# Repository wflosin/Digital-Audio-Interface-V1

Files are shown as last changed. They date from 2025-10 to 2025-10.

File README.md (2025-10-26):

This is a complete design for a digital audio interface. The features include:
- 1/4" jack input (mono)
- Headphone output (loobpack or computer audio output)
- Active tone control, three knobs (bass, mid, treble) 
- Active volume control
- Clipping indicator
- HID buttons (mute, volume up, volume down)
- Entirely USB-powered
- No screws needed, the panel snap fits into the enclosure

What is found in this repository:
- Schematic and Board files (Eagle CAD)
- Images of the schematic and board
- Parts list, and Digikey order
- Gerber files
- 3D models for the enclosure, and potentiometer and button caps

The circuit uses the audio codex PCM2906 from TI, which includes a USB interface. Although many of the parts can be hand-soldered, it is recoommended to reflow solder the board. 

The overall cost of parts and printing was approximately $115 CAD (Oct-2025). Parts were selected to minimize noise thorughout the circuit, and so cheaper alternatives could be used instead. 
Parts were ordered through Digikey and from Texas Instruments. The enclosure was 3D printed, but a metal enclosure could probe useful for shielding. 

Notable issues to be improved on in the next iteration: 
- Headphone pop when plugging in
- When the bass tone control is turned up too high, all sound cuts out
- When listening through headphones on the loobback setting, the only way to control the headphone volume is with the gain knob. This should have a separate volume control. 

Noise and performance metrics of the board were not evaluated once completed. Audio quality was sufficient for this iteration, but naturally, performance metrics are a must potentially commercializable devices. 

I hope you like it!

Below are several sources that helped in the creation of this design:
- https://www.theseus.fi/bitstream/handle/10024/857714/Heikkinen_Tuomas-Pyry.pdf
- https://kastner.ucsd.edu/ryan/wp-content/uploads/sites/5/2022/06/admin/usb-audio-interface.pdf
- https://guitarnuts2.proboards.com/thread/7842/modeling-electric-guitar-ltspice
- https://circuitdigest.com/electronic-circuits/audio-equalizer-tone-control-circuit-with-bass-treble-and-mid-frequency-control
- https://www.ti.com/lit/ug/tidu034/tidu034.pdf
- Small Signal Audio Design, by Douglas Self (chapter 9)
- https://www.edn.com/signal-distortion-from-high-k-ceramic-capacitors/

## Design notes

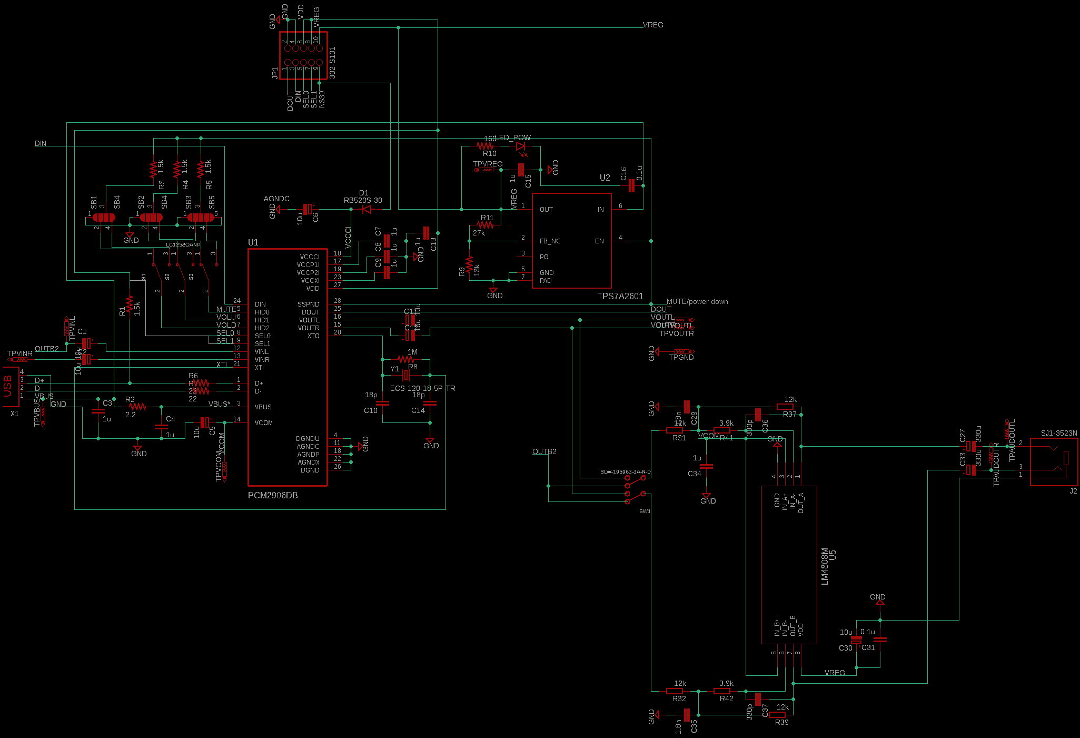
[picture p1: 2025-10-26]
DAI_V1.1_schematic_sheet1.png

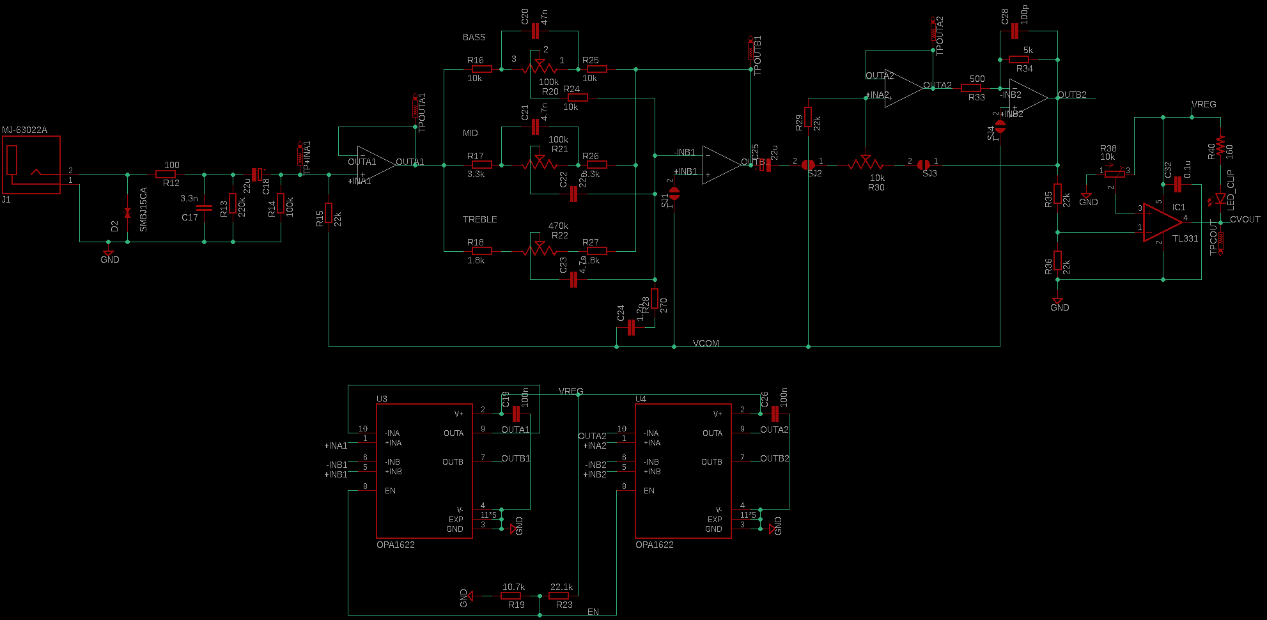
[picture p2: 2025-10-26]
DAI_V1.1_schematic_sheet2.png

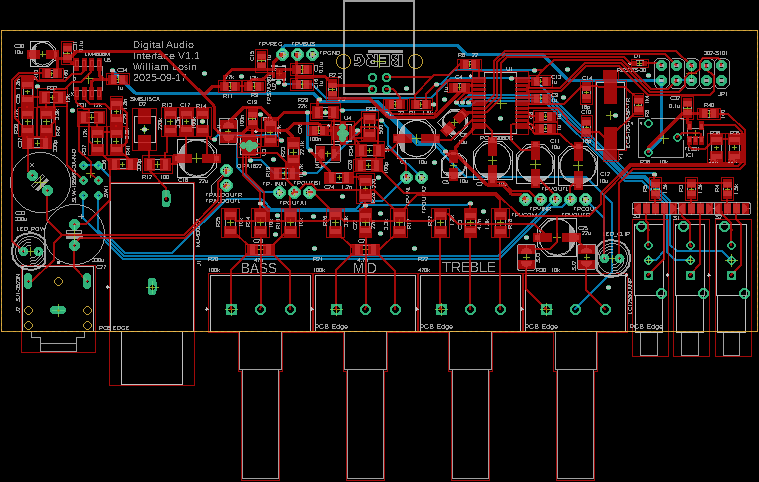
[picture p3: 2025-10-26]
DAI_V1.1_board.png

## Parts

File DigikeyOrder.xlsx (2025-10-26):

# | QUANTITY | PART NUMBER | MANUFACTURER PART NUMBER | DESCRIPTION | CUSTOMER REFERENCE | BACKORDER | UNIT PRICE | EXTENDED PRICE
1 | 1 | 118-PDB181-K425K-103B-ND | PDB181-K425K-103B | POT 10K OHM 1/5W CARBON LINEAR |  | 0 | 1.89 | 1.89
2 | 2 | 2223-PTN16-A100125K1B1-ND | PTN16-A100125K1B1 | POT 100K OHM 1/8W CARBON LINEAR |  | 0 | 1.76 | 3.52
3 | 1 | 2223-PTN16-A500125K1B1-ND | PTN16-A500125K1B1 | POT 500K OHM 1/8W CARBON LINEAR |  | 0 | 1.76 | 1.76
4 | 1 | 609-3657-ND | 61729-1011BLF | CONN RCPT USB2.0 TYPEB 4POS R/A |  | 0 | 1.7 | 1.70
5 | 4 | 732-5317-ND | 61300411121 | CONN HEADER VERT 4POS 2.54MM |  | 0 | 0.25 | 1.00
6 | 10 | 2057-RS1-02-G-ND | RS1-02-G | RECEPTACLE STRIP 2P 2.54MM PITCH |  | 0 | 0.207 | 2.07
7 | 1 | XC717CT-ND | ECS-120-18-5P-TR | CRYSTAL 12.0000MHZ 18PF SMD |  | 0 | 1.1 | 1.10
8 | 3 | EG5887-ND | LC1258OANP | SWITCH PUSHBUTTON SPDT 0.3A 30V |  | 0 | 1.65 | 4.95
9 | 1 | CP1-3523N-ND | SJ1-3523N | CONN JACK STEREO 3.5MM R/A |  | 0 | 1.21 | 1.21
10 | 1 | RB520S-30-TPMSCT-ND | RB520S-30-TP | DIODE SCHOTTKY 30V 200MA SOD523 |  | 0 | 0.25 | 0.25
11 | 1 | SMBJ15CALFCT-ND | SMBJ15CA | TVS DIODE 15VWM 24.4VC DO214AA |  | 0 | 0.52 | 0.52
12 | 1 | 296-10168-1-ND | TL331IDBVR | IC COMPARATOR 1 DIFF SOT23-5 |  | 0 | 0.67 | 0.67
13 | 1 | 754-1217-ND | WP3A8GD | LED GREEN DIFFUSED T-1 T/H |  | 0 | 0.33 | 0.33
14 | 1 | 754-1212-ND | WP132XYD | LED YELLOW DIFFUSED T-1 T/H |  | 0 | 0.4 | 0.40
15 | 1 | 2223-SLW-195963-3A-N-D-ND | SLW-195963-3A-N-D | 19.5 X 9 X 6.3 MM, 3 MM RAISED S |  | 0 | 0.68 | 0.68
16 | 2 | 493-15141-ND | UFW1H331MPD | CAP ALUM 330UF 20% 50V RADIAL TH |  | 0 | 1.12 | 2.24
17 | 1 | ED1543-ND | 302-S101 | CONN HEADER VERT 10POS 2.54MM |  | 0 | 0.38 | 0.38
18 | 1 | 2223-MJ-63022A-ND | MJ-63022A | AUDIO JACK, 6.35 MM, HORIZONTAL, |  | 0 | 1.85 | 1.85
19 | 1 | 296-35280-1-ND | LM4808MX/NOPB | IC AMP CLASS AB STER 150MW 8SOIC |  | 0 | 1.24 | 1.24
20 | 1 | 541-4192-1-ND | CRCW1206270RFKEAC | RES SMD 270 OHM 1% 1/4W 1206 | R28 | 0 | 0.16 | 0.16
21 | 1 | 118-CR1206-FX-5100ELFCT-ND | CR1206-FX-5100ELF | RES SMD 510 OHM 1% 1/4W 1206 | R33 | 0 | 0.16 | 0.16
22 | 2 | 311-1.80KFRCT-ND | RC1206FR-071K8L | RES 1.8K OHM 1% 1/4W 1206 | R18, R27 | 0 | 0.16 | 0.32
23 | 2 | 541-4191-1-ND | CRCW12063K30FKEAC | RES SMD 3.3K OHM 1% 1/4W 1206 | R17, R26 | 0 | 0.16 | 0.32
24 | 1 | CR1206-FX-5101ELFCT-ND | CR1206-FX-5101ELF | RES SMD 5.1K OHM 1% 1/4W 1206 | R34 | 0 | 0.16 | 0.16
25 | 3 | 311-10.0KFRCT-ND | RC1206FR-0710KL | RES 10K OHM 1% 1/4W 1206 | R16, R24, R25 | 0 | 0.16 | 0.48
26 | 4 | A129826CT-ND | CRGCQ1206F22K | RES 22K OHM 1% 1/4W 1206 | R15, R29/R35, R36 | 0 | 0.16 | 0.64
27 | 1 | 311-100KFRCT-ND | RC1206FR-07100KL | RES 100K OHM 1% 1/4W 1206 | R14 | 0 | 0.16 | 0.16
28 | 1 | 311-220KFRCT-ND | RC1206FR-07220KL | RES 220K OHM 1% 1/4W 1206 | R13 | 0 | 0.16 | 0.16
29 | 2 | RMCF1206FT3K90CT-ND | RMCF1206FT3K90 | RES 3.9K OHM 1% 1/4W 1206 | R41, R42 | 0 | 0.16 | 0.32
30 | 1 | P20755CT-ND | ERJ-PB6B2702V | RES SMD 27K OHM 0.1% 1/4W 0805 | R11 | 0 | 0.33 | 0.33
31 | 1 | P20720CT-ND | ERJ-PB6B1302V | RES SMD 13K OHM 0.1% 1/4W 0805 | R9 | 0 | 0.33 | 0.33
32 | 2 | 2019-RK73H2ATTD1600FCT-ND | RK73H2ATTD1600F | RES 160 OHM 1% 1/4W 0805 | R10, R40 | 0 | 0.16 | 0.32
33 | 1 | 2019-RK73H2ATTD2R20FCT-ND | RK73H2ATTD2R20F | RES 2.2 OHM 1% 1/4W 0805 | R2 | 0 | 0.16 | 0.16
34 | 2 | 2019-RK73H2ATTD22R0FCT-ND | RK73H2ATTD22R0F | RES 22 OHM 1% 1/4W 0805 | R6, R7 | 0 | 0.16 | 0.32
35 | 1 | 2019-RK73H2ATTD1004FCT-ND | RK73H2ATTD1004F | RES 1M OHM 1% 1/4W 0805 | R8 | 0 | 0.16 | 0.16
36 | 4 | 2019-RK73H2ATTD1501FCT-ND | RK73H2ATTD1501F | RES 1.5K OHM 1% 1/4W 0805 | R1, R3, R4, R5 | 0 | 0.16 | 0.64
37 | 1 | 2019-RK73H2BTTD1072FCT-ND | RK73H2BTTD1072F | RES 10.7K OHM 1% 1/4W 1206 | R19 | 0 | 0.16 | 0.16
38 | 1 | 2019-RK73H2BTTD2212FCT-ND | RK73H2BTTD2212F | RES 22.1K OHM 1% 1/4W 1206 | R23 | 0 | 0.16 | 0.16
39 | 10 | 2019-RK73H2BTTD1202FCT-ND | RK73H2BTTD1202F | RES 12K OHM 1% 1/4W 1206 | R31, R32, R37, R39 | 0 | 0.061 | 0.61
40 | 1 | 1276-3259-1-ND | CL31C332JHHNFNE | CAP CER 3300PF 630V C0G/NP0 1206 | C17 | 0 | 0.2 | 0.20
41 | 2 | 490-GCM3195C2A472GA16DCT-ND | GCM3195C2A472GA16D | CAP CER 4700PF 100V C0G/NP0 1206 | C21, C23 | 0 | 0.36 | 0.72
42 | 1 | 490-GRM3195C2A473GA01DCT-ND | GRM3195C2A473GA01D | CAP CER 47000PF 100V C0G 1206 | C20 | 0 | 0.96 | 0.96
43 | 1 | 490-GRT3195C2A223JA02DCT-ND | GRT3195C2A223JA02D | CAP CER 0.022UF 100V C0G 1206 | C22 | 0 | 0.51 | 0.51
44 | 1 | 13-CC1206FRNPO9BN122CT-ND | CC1206FRNPO9BN122 | CAP CER 1200PF 50V C0G/NPO 1206 | C24 | 0 | 0.66 | 0.66
45 | 1 | 720-VJ1206A101JXGCW1HVCT-ND | VJ1206A101JXGCW1HV | CAP CERAMIC 100PF 1KV C0G NP0 | C28 | 0 | 0.19 | 0.19
46 | 2 | 13-CC1206GRNPO9BN182CT-ND | CC1206GRNPO9BN182 | CAP CER 1800PF 50V C0G/NPO 1206 | C29, C35 | 0 | 0.5 | 1.00
47 | 2 | 1276-1846-1-ND | CL31C331JBCNNNC | CAP CER 330PF 50V C0G/NP0 1206 | C36, C37 | 0 | 0.22 | 0.44
48 | 4 | 732-8327-1-ND | 865250643009 | CAP ALUM 10UF 20% 50V SMD | C1, C2/C11, C12 | 0 | 0.58 | 2.32
49 | 2 | 732-8353-1-ND | 865250543005 | CAP ALUM 22UF 20% 35V SMD | C18, C25 | 0 | 0.6 | 1.20
50 | 3 | 732-8430-1-ND | 865080440002 | CAP ALUM 10UF 20% 25V SMD | C5, C6, C30 | 0 | 0.26 | 0.78
51 | 10 | 1276-1029-1-ND | CL21B105KBFNNNE | CAP CER 1UF 50V X7R 0805 | C3, C4, C7, C8, C9, C13, C15, C34 | 0 | 0.019 | 0.19
52 | 10 | 478-KGM21NR71H104KTCT-ND | KGM21NR71H104KT | CAP CER 0.1UF 50V X7R 0805 | C16, C19, C26, C31, C32 | 0 | 0.013 | 0.13
53 | 2 | 311-1102-1-ND | CC0805JRNPO9BN180 | CAP CER 18PF 50V C0G/NPO 0805 | C10, C14 | 0 | 0.15 | 0.30
54 | 1 | 311-100FRCT-ND | RC1206FR-07100RL | RES 100 OHM 1% 1/4W 1206 | R12 | 0 | 0.16 | 0.16

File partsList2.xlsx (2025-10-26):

Partlist
Exported from DAI_V1.brd at 2025-09-17 1:20 AM
 |  |  | Components on audio path
EAGLE Version 9.6.2 Copyright (c) 1988-2020 Autodesk, Inc. |  |  | Page 2
 |  |  | Page 1
Assembly variant:
 |  |  |  |  |  |  | $40.52
 |  |  |  |  |  |  | $68.78
Part | Value | Device | Description | Price per unit | Required quantity | Tentative quantity | Total Cost | Aquired | Link
R2 | 2.2 | RES 2.2 OHM 1% 1/4W 0805 | VBUS | $0.16 | 1 | 1 | $0.16
R6, R7 | 22 | RES 22 OHM 1% 1/4W 0805 | USB data | $0.16 | 2 | 2 | $0.32
R12 | 100 | RES 100 OHM 1% 1/4W 1206 | RF Filter | $0.16 | 1 | 1 | $0.16
R10, R40 | 160 | RES 160 OHM 1% 1/4W 0805 | LED Resistors | $0.16 | 2 | 2 | $0.32
R28 | 270 | RES SMD 270 OHM 1% 1/4W 1206 | Tone EQ | $0.16 | 1 | 1 | $0.16
R33 | 510 | RES SMD 510 OHM 1% 1/4W 1206 | Baxandall | $0.16 | 1 | 1 | $0.16
C16, C19, C26, C31, C32 | 0.1u | CAP CER 0.1UF 50V X7R 0805 | Bypass caps | $0.01 | 5 | 10 | $0.13
C24 | 1.2n | CAP CER 1200PF 50V C0G/NPO 1206 | Tone EQ | $0.66 | 1 | 1 | $0.66
R1, R3, R4, R5 | 1.5k | RES 1.5K OHM 1% 1/4W 0805 | Pullup? | $0.16 | 4 | 4 | $0.64
R18, R27 | 1.8k | RES 1.8K OHM 1% 1/4W 1206 | Treble | $0.16 | 2 | 2 | $0.32
C29, C35 | 1.8n | CAP CER 1800PF 50V C0G/NPO 1206 | Headphone caps, C0G | $0.50 | 2 | 2 | $1.00
R19 | 10.7k | RES 10.7K OHM 1% 1/4W 1206 | EN stabilizer | $0.16 | 1 | 1 | $0.16
R14 | 100k | RES 100K OHM 1% 1/4W 1206 | RF Filter | $0.16 | 1 | 1 | $0.16
R20, R21 | 100k | POT_PTN16-A100125K1B1 | rotary potentiometer | $1.76 | 2 | 2 | $3.52
C28 | 100p | CAP CERAMIC 100PF 1KV C0G NP0 | Baxandall | $0.19 | 1 | 1 | $0.19
R16, R24, R25 | 10k | RES 10K OHM 1% 1/4W 1206 | Bass | $0.16 | 3 | 3 | $0.48
R30 | 10k | POT_PDB181-K425K-103B | rotary potentiometer | $1.89 | 1 | 1 | $1.89
R38 | 10k | 601030 | Clipping set point |  | 0 | 0 | $0.00
C1, C2/C11, C12 | 10u | PANASONIC_D. CAP ALUM 10UF 20% 50V SMD | VINL/R/VOUTL/R coupling caps, bipolar | $0.58 | 4 | 4 | $2.32
C5, C6, C30 | 10u | PANASONIC_B, CAP ALUM 10UF 20% 25V SMD | Bypass caps | $0.26 | 3 | 3 | $0.78
R31, R32, R37, R39 | 12k | RES 12K OHM 1% 1/4W 1206 | Headphone resistors | $0.06 | 4 | 10 | $0.61
R9 | 13k | RES SMD 13K OHM 0.1% 1/4W 0805 | VREG voltage divider | $0.33 | 1 | 1 | $0.33
C10, C14 | 18p | CAP CER 18PF 50V C0G/NPO 0805 | Crystal caps | $0.15 | 2 | 2 | $0.30
R8 | 1M | RES 1M OHM 1% 1/4W 0805 | Crystal resistor | $0.16 | 1 | 1 | $0.16
C3, C4, C7, C8, C9, C13, C15, C34 | 1u | CAP CER 1UF 50V X7R 0805 | Bypass caps/filters | $0.02 | 8 | 10 | $0.19
R23 | 22.1k | RES 22.1K OHM 1% 1/4W 1206 | EN stabilizer | $0.16 | 1 | 1 | $0.16
R13 | 220k | RES 220K OHM 1% 1/4W 1206 | RF Filter | $0.16 | 1 | 1 | $0.16
R15, R29/R35, R36 | 22k | RES 22K OHM 1% 1/4W 1206 | Bias Resistor/comp V divider | $0.16 | 4 | 4 | $0.64
C22 | 22n | CAP CER 0.022UF 100V C0G 1206 | Mid | $0.51 | 1 | 1 | $0.51
C18/C25 | 22u | PANASONIC_D, CAP ALUM 22UF 20% 35V SMD | RF Filter/Interstage coupling, bipolar | $0.60 | 2 | 2 | $1.20
R11 | 27k | RES SMD 27K OHM 0.1% 1/4W 0805 | VREG voltage divider | $0.33 | 1 | 1 | $0.33
R17, R26 | 3.3k | RES SMD 3.3K OHM 1% 1/4W 1206 | Mid | $0.16 | 2 | 2 | $0.32
C17 | 3.3n | CAP CER 3300PF 630V C0G/NP0 1206 | RF Filter | $0.20 | 1 | 1 | $0.20
R41, R42 | 3.9k | RES 3.9K OHM 1% 1/4W 1206 | Headphone resistors | $0.16 | 2 | 2 | $0.32
C36, C37 | 330p | CAP CER 330PF 50V C0G/NP0 1206 | Headphone caps, C0G | $0.22 | 2 | 2 | $0.44
C27, C33 | 330u | E3,5-10 | Headphone coupling cap | $1.12 | 2 | 2 | $2.24
C21, C23 | 4.7n | CAP CER 4700PF 100V C0G/NP0 1206 | Mid/Treble caps | $0.36 | 2 | 2 | $0.72
C20 | 47n | CAP CER 47000PF 100V C0G 1206 | Bass cap | $0.96 | 1 | 1 | $0.96
R34 | 5.1k | RES SMD 5.1K OHM 1% 1/4W 1206 | Baxandall | $0.16 | 1 | 1 | $0.16
R22 | 500k | POT_PTN16-A500125K1B1 | rotary potentiometer | $1.76 | 1 | 1 | $1.76
Y1 | ECS-120-18-5P-TR | XTAL_ECS-120-18-5P-TR | Crystal for clock | $1.10 | 1 | 1 | $1.10
S1, S2, S3 | LC1258OANP | SW_LC1258EENP | HID pushbutton | $1.65 | 3 | 3 | $4.95
U5 | LM4808M | M08A | Headphone amplifier | $1.24 | 1 | 1 | $1.24
J1 | MJ-63022A | MJ-63022A | 1/4" Jack, mono | $1.85 | 1 | 1 | $1.85
U3, U4 | OPA1622 | IC_OPA1622IDRCR | Audio op amp | $7.07 | 2 | 2 | $14.14
U1 | PCM2906DB | SOP65P780X200-28N | TI USB Codec | $12.51 | 1 | 1 | $12.51
D1 | RB520S-30 | DIO_RB520S-30 | VREG Schottky diode | $0.25 | 1 | 1 | $0.25
J2 | SJ1-3523N | CUI_SJ1-3523N | 3.5mm phone jack | $1.21 | 1 | 1 | $1.21
SW1 | SLW-195963-3A-N-D | SW-T3-4B-A-A3-S2 | DPDT Switch | $0.68 | 1 | 1 | $0.68
D2 | SMBJ15CA | DIOM4336X265N | TVS Diode | $0.52 | 1 | 1 | $0.52
IC1 | TL331 | DBV-R-PDSO-G5 | Comparator | $0.67 | 1 | 1 | $0.67
U2 | TPS7A2601 | DRV0006A_NV | TI Voltage regulator | $1.61 | 1 | 1 | $1.61
JP1 |  | 2X05 | Test headers | $0.38 | 1 | 1 | $0.38
LED_CLIP |  | LED5MM | Yellow | $0.40 | 1 | 1 | $0.40
LED_POW |  | LED5MM | Green | $0.33 | 1 | 1 | $0.33
X1 |  | PN61729 | USB | $1.70 | 1 | 1 | $1.70

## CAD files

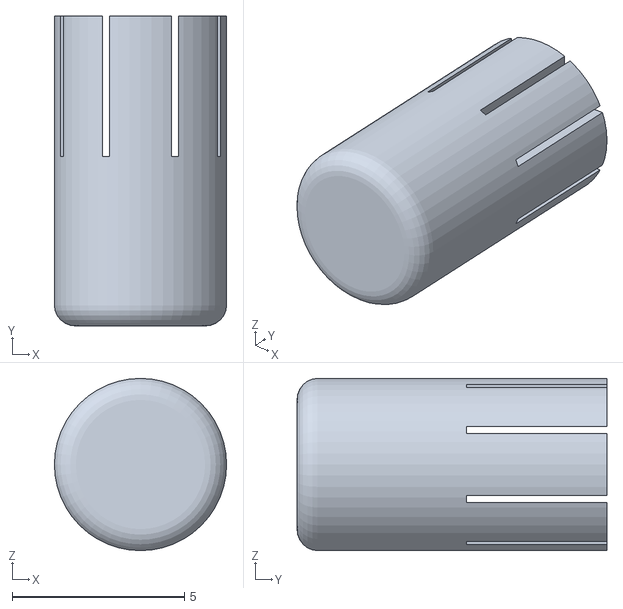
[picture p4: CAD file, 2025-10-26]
3DModels/5mmx9mmLCButtonCap.stl
5.00 x 9.00 x 5.00

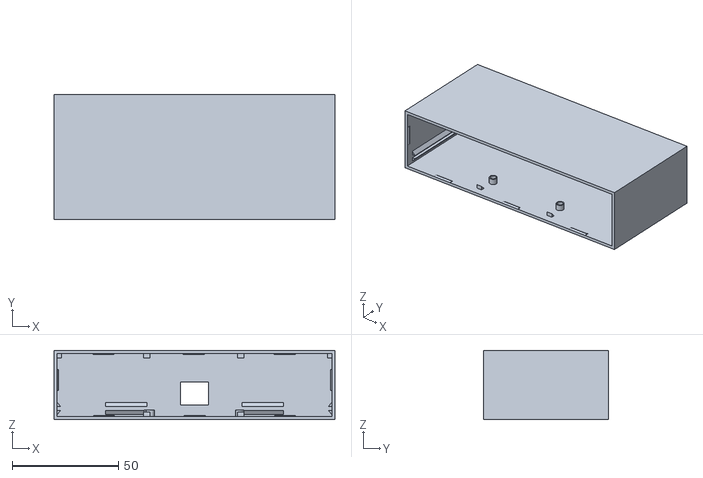
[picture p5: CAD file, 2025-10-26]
3DModels/Enclosure_1.5mmWalls_3.stl
132.0 x 58.5 x 32.6

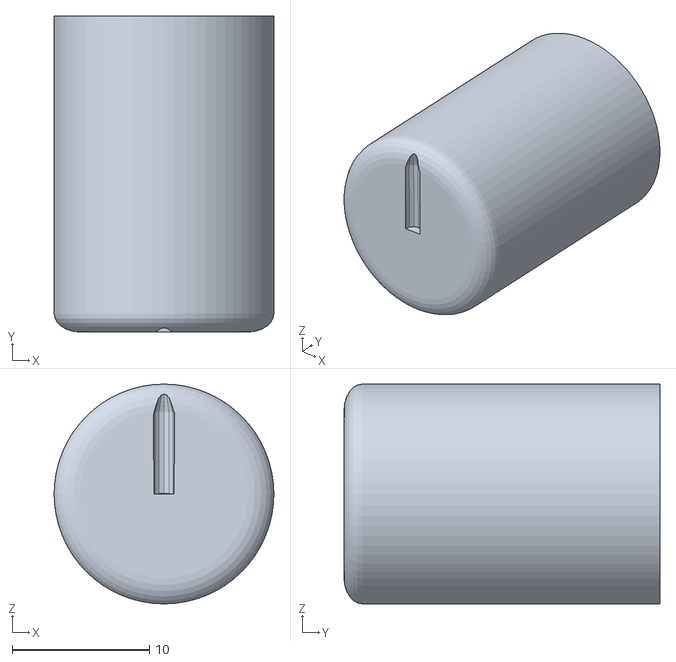
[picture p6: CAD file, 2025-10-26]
3DModels/PotCap3.stl
16.0 x 23.0 x 16.0

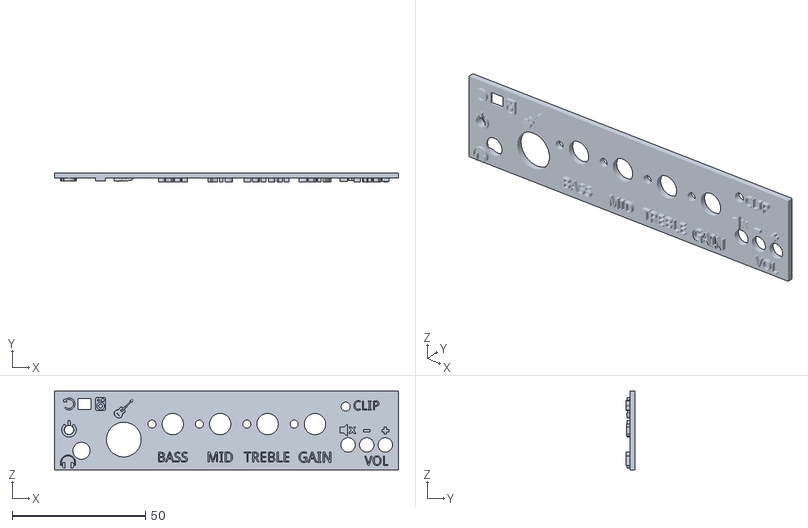
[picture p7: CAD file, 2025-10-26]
3DModels/FrontPanel3_thintxt.stl
129.0 x 3.45 x 29.6

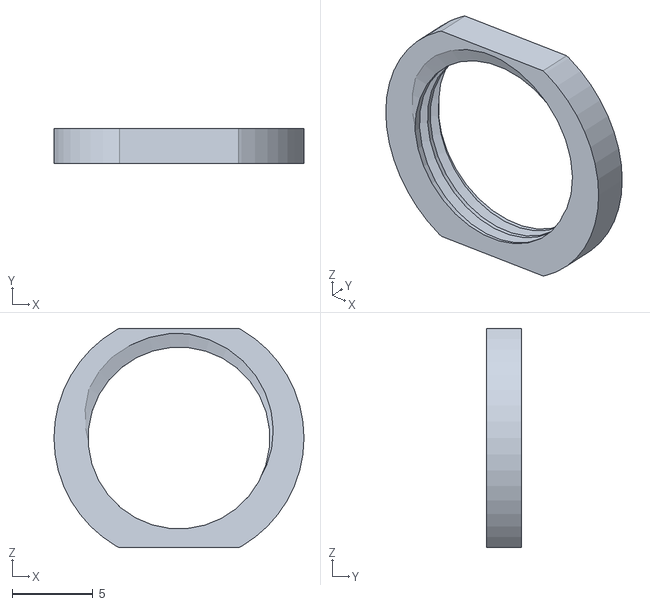
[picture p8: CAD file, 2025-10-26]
3DModels/M12washerP1_OD15mm5_2.stl
15.5 x 2.20 x 13.6

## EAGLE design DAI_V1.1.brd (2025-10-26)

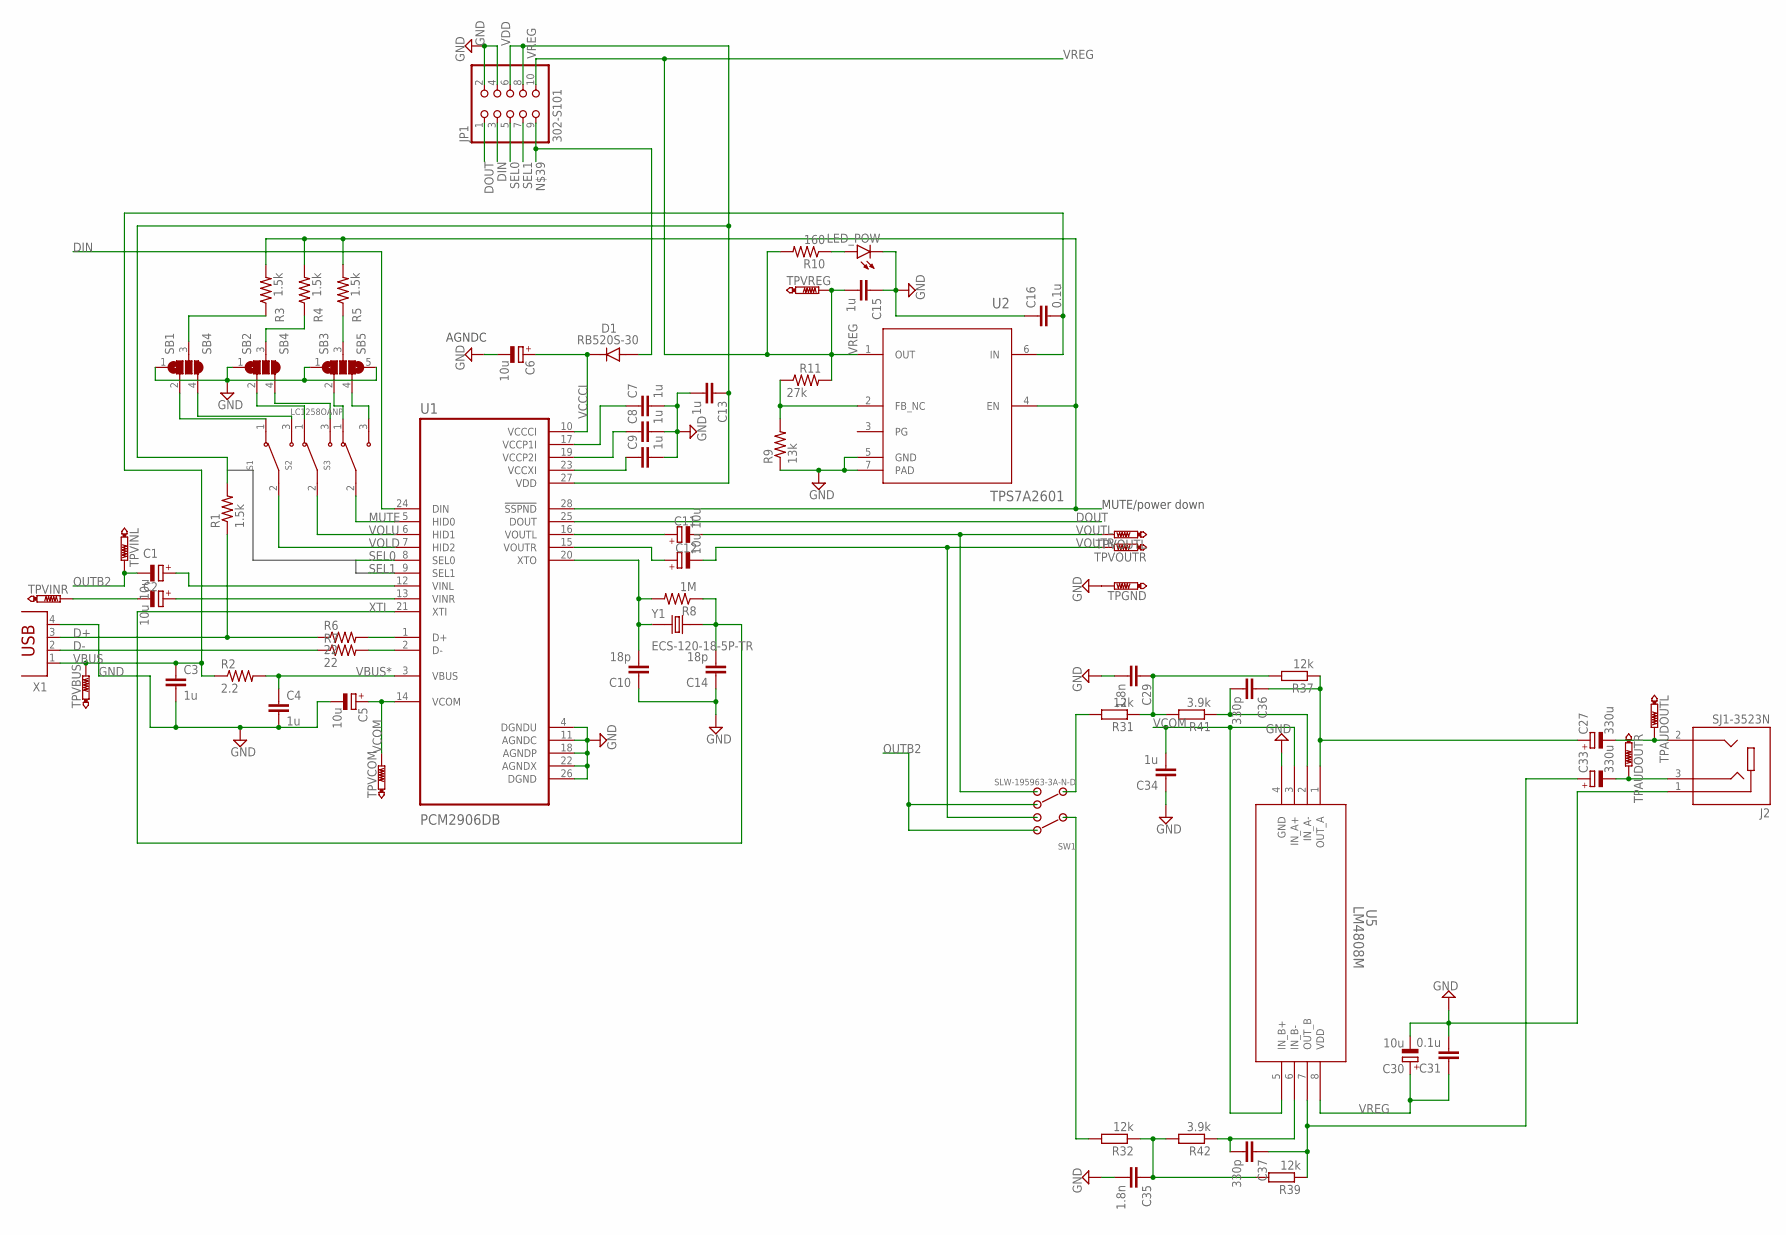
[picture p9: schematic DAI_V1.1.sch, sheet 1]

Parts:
C1, C2, C11, C12: 10u; PANASONIC_D
C3, C4, C7, C8, C9, C13, C15, C34: 1u; C0805
C5, C6, C30: 10u; PANASONIC_B
C10, C14: 18p; C0805
C16, C31: 0.1u; C0805
C27, C33: 330u; E3,5-10
C29, C35: 1.8n; C1206
C36, C37: 330p; C1206
D1: RB520S-30; DIO_RB520S-30
J2: SJ1-3523N; CUI_SJ1-3523N
JP1: 302-S101; 2X05
LED_POW: LED5MM
R1, R3, R4, R5: 1.5k; R0805
R2: 2.2; R0805
R6, R7: 22; R0805
R8: 1M; R0805
R9: 13k; R0805
R10: 160; R0805
R11: 27k; R0805
R31, R32, R37, R39: 12k; M1206
R41, R42: 3.9k; M1206
S1, S3: LC1258EENP; SW_LC1258EENP
S2: LC1258OANP; SW_LC1258EENP
SB1, SB2: SB4
SB3: SB5
SW1: SLW-195963-3A-N-D; SW-T3-4B-A-A3-S2
TPAUDOUTL: PTR1PAD1-13; P1-13
TPAUDOUTR: PTR1PAD1-13; P1-13
TPGND: PTR1PAD1-13; P1-13
TPVBUS: PTR1PAD1-13; P1-13
TPVCOM: PTR1PAD1-13; P1-13
TPVINL: PTR1PAD1-13; P1-13
TPVINR: PTR1PAD1-13; P1-13
TPVOUTL: PTR1PAD1-13; P1-13
TPVOUTR: PTR1PAD1-13; P1-13
TPVREG: PTR1PAD1-13; P1-13
U1: PCM2906DB; SOP65P780X200-28N
U2: TPS7A2601; DRV0006A_NV
U5: LM4808M; M08A
X1: PN61729
Y1: ECS-120-18-5P-TR; XTAL_ECS-120-18-5P-TR

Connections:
AUDOUTL: C27.-, J2.2, TPAUDOUTL.TP
AUDOUTR: C33.-, J2.3, TPAUDOUTR.TP
D+: R1.1, R6.1, X1.3
D-: R7.1, X1.2
DIN: JP1.3, U1.24 (DIN)
DOUT: JP1.1, U1.25 (DOUT)
GND: C3.2, C4.2, C5.-, C6.-, C7.2, C8.2, C9.2, C10.1, C13.2, C14.1, C15.1, C16.1, C29.2, C30.-, C31.2, C34.1, C35.2, J2.1, JP1.2, JP1.4, LED_POW.K (C), R9.1, SB1.1, SB2.1, SB3.1, SB3.5, TPGND.TP, U1.4 (DGNDU), U1.11 (AGNDC), U1.18 (AGNDP), U1.22 (AGNDX), U1.26 (DGND), U2.5 (GND), U2.7 (PAD), U5.4 (GND), X1.4; also elsewhere on the board
MUTE: S3.2 (COM), U1.5 (HID0)
unnamed: R6.2, U1.1 (D+)
unnamed: R7.2, U1.2 (D-)
unnamed: R32.2, SW1.2
unnamed: R3.1, SB1.3
unnamed: C29.1, R31.1, R37.2, R41.2
unnamed: R5.1, SB3.3
unnamed: LED_POW.A, R10.1
unnamed: C35.1, R32.1, R39.2, R42.2
unnamed: C33.+, C37.1, R39.1, U5.7 (OUT_B)
unnamed: R4.1, SB2.3
unnamed: S1.1 (NC), SB1.2
unnamed: R9.2, R11.1, U2.2 (FB_NC)
unnamed: C11.+, U1.16 (VOUTL)
unnamed: C12.+, U1.15 (VOUTR)
unnamed: S1.3 (NO), SB1.4
unnamed: S2.1 (NC), SB2.2
unnamed: S2.3 (NO), SB2.4
unnamed: S3.1 (NC), SB3.2
unnamed: S3.3 (NO), SB3.4
unnamed: C36.2, R41.1, U5.2 (IN_A-)
unnamed: R31.2, SW1.5
unnamed: C27.+, C36.1, R37.1, U5.1 (OUT_A)
unnamed: D1.A, JP1.9
unnamed: C37.2, R42.1, U5.6 (IN_B-)
OUTB2: C1.-, SW1.1, SW1.4, TPVINL.TP; also elsewhere on the board
SEL0: JP1.5, U1.8 (SEL0)
SEL1: JP1.7, U1.9 (SEL1)
SSPND: R3.2, R4.2, R5.2, U1.28 (!SSPND), U2.4 (EN)
VBUS: C3.1, C16.2, R2.1, TPVBUS.TP, U2.6 (IN), X1.1
VBUS*: C4.1, R2.2, U1.3 (VBUS)
VCCCI: C6.+, D1.C (K), U1.10 (VCCCI)
VCCP1I: C7.1, U1.17 (VCCP1I)
VCCP2I: C8.1, U1.19 (VCCP2I)
VCCXI: C9.1, U1.23 (VCCXI)
VCOM: C5.+, C34.2, TPVCOM.TP, U1.14 (VCOM), U5.3 (IN_A+), U5.5 (IN_B+); also elsewhere on the board
VDD: C13.1, JP1.6, JP1.8, R1.2, U1.27 (VDD)
VINL: C1.+, U1.12 (VINL)
VINR: C2.-, TPVINR.TP
VINR*: C2.+, U1.13 (VINR)
VOLD: S1.2 (COM), U1.7 (HID2)
VOLU: S2.2 (COM), U1.6 (HID1)
VOUTL: C11.-, SW1.6, TPVOUTL.TP
VOUTR: C12.-, SW1.3, TPVOUTR.TP
VREG: C15.2, C30.+, C31.1, JP1.10, R10.2, R11.2, TPVREG.TP, U2.1 (OUT), U5.8 (VDD); also elsewhere on the board
XTI: C14.2, R8.1, U1.21 (XTI), Y1.2
XTO: C10.2, R8.2, U1.20 (XTO), Y1.1

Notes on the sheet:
MUTE/power down
AGNDC

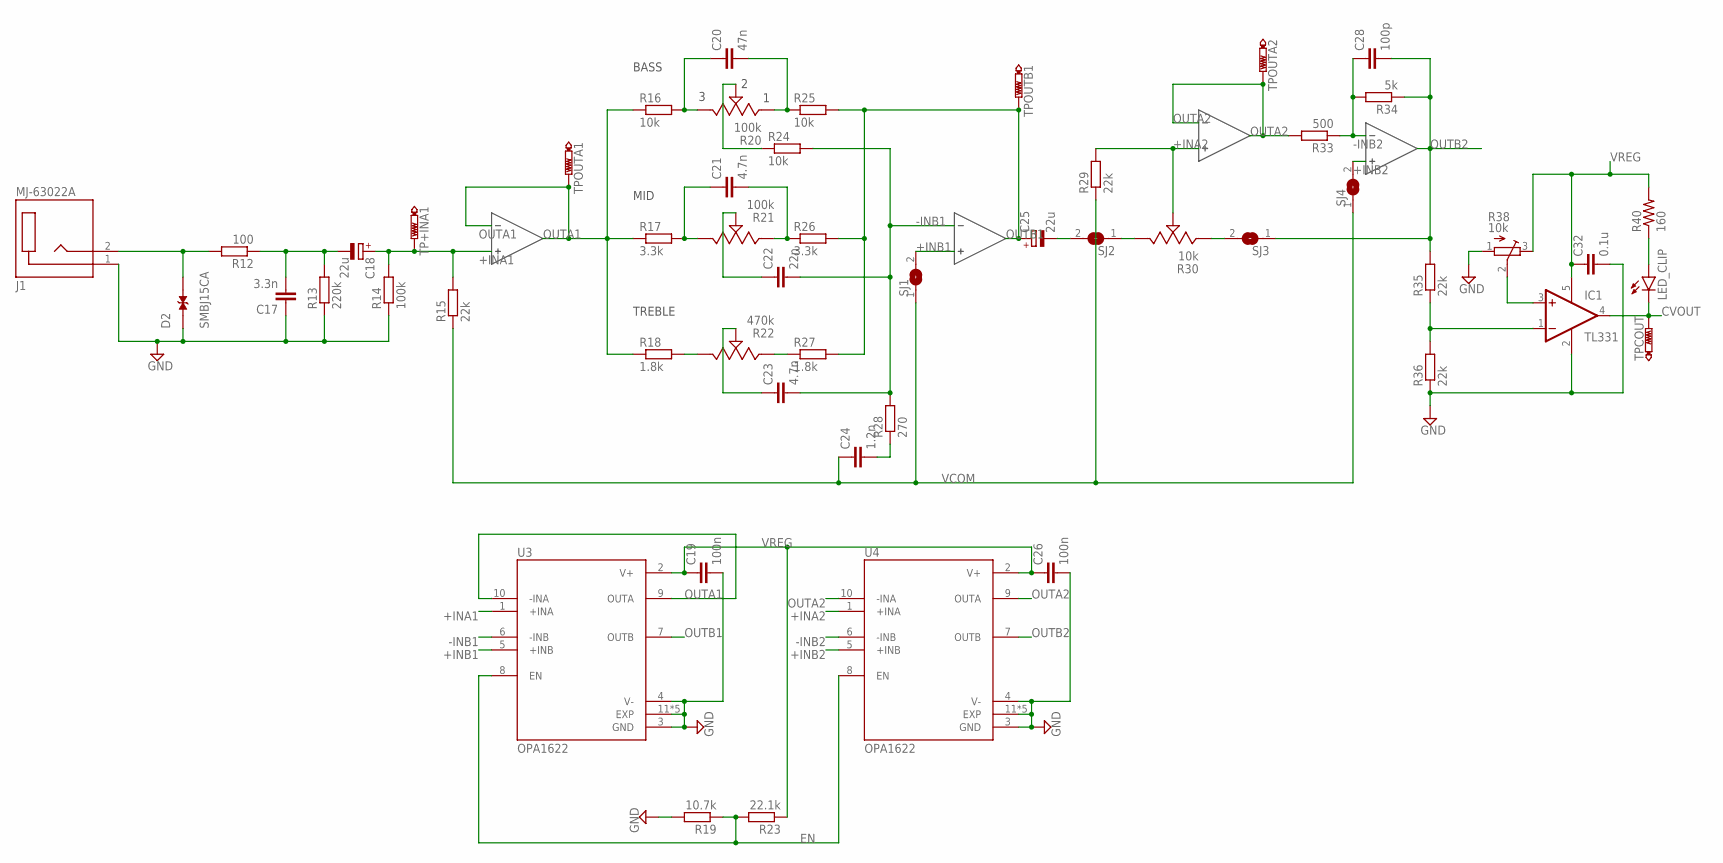
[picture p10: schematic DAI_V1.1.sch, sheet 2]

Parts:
C17: 3.3n; C1206
C18, C25: 22u; PANASONIC_D
C19, C26: 100n; C0805
C20: 47n; C1206
C21, C23: 4.7n; C1206
C22: 22n; C1206
C24: 1.2n; C1206
C28: 100p; C1206
C32: 0.1u; C0805
D2: SMBJ15CA; DIOM4336X265N
IC1: TL331; DBV-R-PDSO-G5
J1: MJ-63022A; CUI_MJ-63022A
LED_CLIP: LED5MM
R12: 100; M1206
R13: 220k; M1206
R14: 100k; M1206
R15, R29, R35, R36: 22k; M1206
R16, R24, R25: 10k; M1206
R17, R26: 3.3k; M1206
R18, R27: 1.8k; M1206
R19: 10.7k; R1206
R20, R21: 100k; POT_PTN16-A100125K1B1
R22: 470k; POT_PTN16-A100125K1B1
R23: 22.1k; R1206
R28: 270; M1206
R30: 10k; POT_PTN16-A100125K1B1
R33: 500; M1206
R34: 5k; M1206
R38: 10k; 601030_AVX
R40: 160; R0805
SJ1, SJ2, SJ3, SJ4: SJW
TP+INA1: PTR1PAD1-13; P1-13
TPCOUT: PTR1PAD1-13; P1-13
TPOUTA1, TPOUTA2: PTR1PAD1-13; P1-13
TPOUTB1: PTR1PAD1-13; P1-13
U3, U4: OPA1622; IC_OPA1622IDRCR

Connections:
+INA1: C18.+, R14.2, R15.2, TP+INA1.TP, U3.1 (+INA)
+INA2: R29.2, R30.2, U4.1 (+INA)
+INB1: SJ1.2, U3.5 (+INB)
+INB2: SJ4.2, U4.5 (+INB)
-INB1: C22.2, C23.2, R24.2, R28.2, U3.6 (-INB)
-INB2: C28.1, R33.1, R34.2, U4.6 (-INB)
CVOUT: IC1.4 (OUT), LED_CLIP.K (C), TPCOUT.TP
EN: R19.1, R23.2, U3.8 (EN), U4.8 (EN)
GND: C17.1, C19.2, C26.2, C32.2, D2.1, IC1.2 (GND), J1.1 (SLEEVE), R13.1, R14.1, R19.2, R36.1, R38.1 (A), U3.3 (GND), U3.4 (V-), U3.11 (EXP), U3.12 (EXP), U3.13 (EXP), U3.14 (EXP), U3.15 (EXP), U4.3 (GND), U4.4 (V-), U4.11 (EXP), U4.12 (EXP), U4.13 (EXP), U4.14 (EXP), U4.15 (EXP); also elsewhere on the board
unnamed: R18.2, R22.3
unnamed: R22.1, R27.1
unnamed: C25.-, SJ2.2
unnamed: D2.2, J1.2 (TIP), R12.2
unnamed: C17.2, C18.-, R12.1, R13.2
unnamed: C21.1, R17.2, R21.3
unnamed: C21.2, R21.1, R26.1
unnamed: R30.3, SJ2.1
unnamed: C20.1, R16.2, R20.3
unnamed: IC1.1 (-IN), R35.1, R36.2
unnamed: C20.2, R20.1, R25.1
unnamed: R20.2, R24.1
unnamed: R30.1, SJ3.2
unnamed: C23.1, R22.2
unnamed: C22.1, R21.2
unnamed: IC1.3 (+IN), R38.2 (S)
unnamed: LED_CLIP.A, R40.1
unnamed: C24.2, R28.1
OUTA1: R16.1, R17.1, R18.1, TPOUTA1.TP, U3.9 (OUTA), U3.10 (-INA)
OUTA2: R33.2, TPOUTA2.TP, U4.9 (OUTA), U4.10 (-INA)
OUTB1: C25.+, R25.2, R26.2, R27.2, TPOUTB1.TP, U3.7 (OUTB)
OUTB2: C28.2, R34.1, R35.2, SJ3.1, U4.7 (OUTB); also elsewhere on the board
VCOM: C24.1, R15.1, R29.1, SJ1.1, SJ4.1; also elsewhere on the board
VREG: C19.1, C26.1, C32.1, IC1.5 (V+), R23.1, R38.3 (E), R40.2, U3.2 (V+), U4.2 (V+); also elsewhere on the board

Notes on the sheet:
BASS
MID
TREBLE

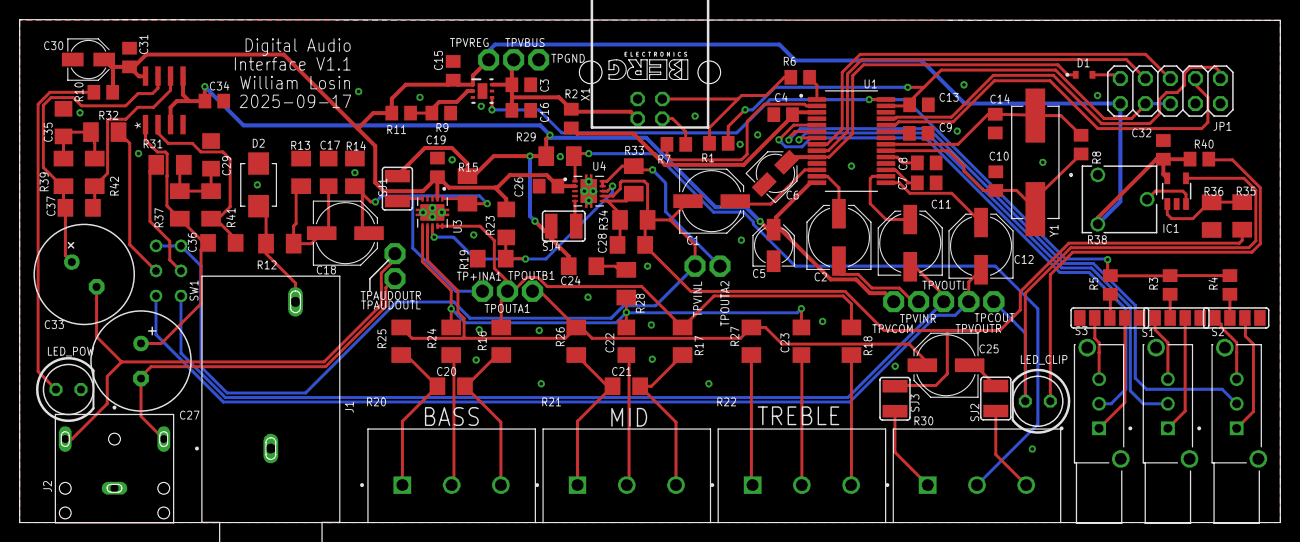
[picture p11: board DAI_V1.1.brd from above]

Board: 2 copper layers, 128.0 x 51.1 mm, 120 parts (0 on the bottom side), 83 nets.

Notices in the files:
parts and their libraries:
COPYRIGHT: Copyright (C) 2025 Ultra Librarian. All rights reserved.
